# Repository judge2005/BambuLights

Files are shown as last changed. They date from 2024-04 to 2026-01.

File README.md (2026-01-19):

# Interface NeoPixels (aka Addressable LED Strip) with Bambu Lab Printers
This project uses common addressable LEDs to add additional lighting for a Bambu printer that can also show the state of the print, e.g.:
* Idle
* Printing
* Complete
* Warning
* Error

In addition it:

* Turns off the LEDs while the X1C is using LIDAR
* Syncronizes with the chamber light - if you turn it off, the additional LEDs will be turned off too
* Support GRB (WS2812x style LEDS) and RGB (APA106 style LEDs)
* Supports an arbitrary number of LEDs
* Auto-registers with Homeassistant so you can (for example) turn the lights on and off on a schedule and control whether they are reactive to the state of the printer or just white

In addition to providing extra lighting for the printer, it could just be used to provide a remote indication of the state
of the printer since it doesn't use a physical connection.
## History
I use the [BLV AMS Riser](https://makerworld.com/en/models/19535) with my Bambu Labs X1C that has a facility for adding
additional lighting, but I also like the idea of the [BLLED project](https://github.com/DutchDevelop/BLLEDController)
that adds lighting that reacts to the state of the printer. I can't use BLLED with the riser because
the LEDs are too big, but I have a lot of experience developing hardware and software that uses ESP32 and 
addressable LEDs so I developed this project to do the same thing, but for 5V WS2812B LED strips.

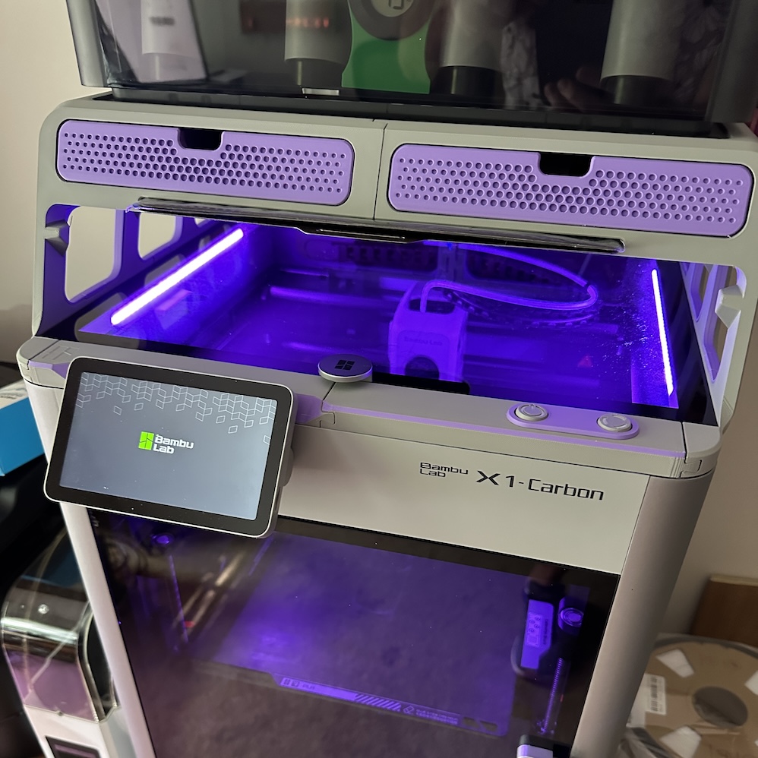
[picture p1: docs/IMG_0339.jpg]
Lights in action

# Software
This project uses PlatformIO IDE. It is easy to build and upload to the hardware if you have PlatformIO installed. Just
check out the repo and open it in PlatformIO. There are builds for three modules:

- ESP32 PICO D4 - this should work on any other 'original' ESP32 module such as the WROOM. This build uses pin 27 for the LED connection by default
- ESP32-S3 - this uses pin 16 by default
- ESP32-C3 - this uses pin 3 by default

There are two artifacts:
- firmware.bin - the firmware!
- littlefs.bin - the GUI

When the software first runs it will create an access point that you can use to connect it to your local network.
The SSID for the access point will be some hex numbers followed by _bambulights_, for example _5FC874bambulights_.
## Installing
Instead of building the software, you can install a release. Go [the latest release](https://github.com/judge2005/BambuLights/releases)
and follow the instructions.
# Hardware
The hardware is pretty simple. The LEDs take less than 0.7A total, so most ESP32 dev kits will be able to provide the
5V power for the LEDs.
## Lights
I used some [high-density WS2812B LED strips available on AliExpress](https://a.aliexpress.com/_mOUCHh0).
They are 5mm flexible LED strips with 160 LEDs/m. They have an adhesive backing so I just left the backing on
so I could slide them in to the channels in the riser. I cut them to 210mm, which is 33 LEDs. The software allows
you to specify how many LEDs you have and also change between GRB (standard for WS2812B strips) and RGB (standard for APA106 strips).

You will need to solder 28AWG hookup wire to the terminals on the strips, preferably white, red and green to match the wiring used in the original
connector. This gauge allows you to thread three wires through the channel in the riser rather than just two.

Wire the two strips in parallel.

I also bought [these JST connectors from AliExpress](https://a.aliexpress.com/_mtc1dYm) so I could easily connect/disconnect the electronics.
The wire colors match the original connector wire colors.
## Electronics
I used a [ESP32 Pico D4 devkit](https://www.amazon.com/DIYmall-ESP32-PICO-KIT-Development-Board-ESP-32/dp/B00RSPTHE0) that I happened to have lying around. The signal from these is
3.3V so I added a [CD40109B level shifter](https://www.ti.com/product/CD40109B). Again I happened to have one lying around, but pretty much any level shifter
would do.

This is how it is wired up:

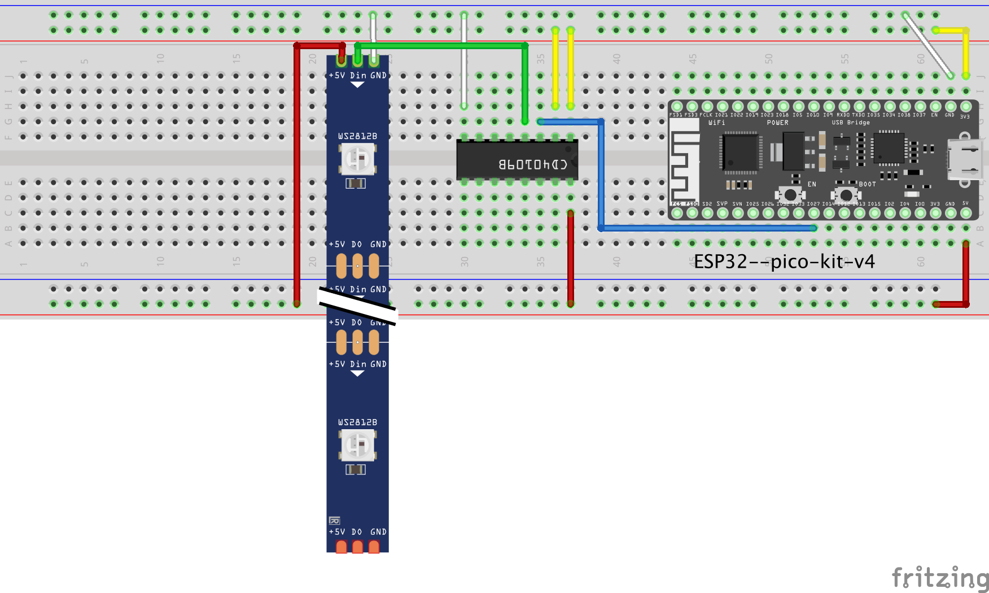
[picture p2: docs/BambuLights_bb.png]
Fritzing diagram


This is the whole thing in a box I printed for it:

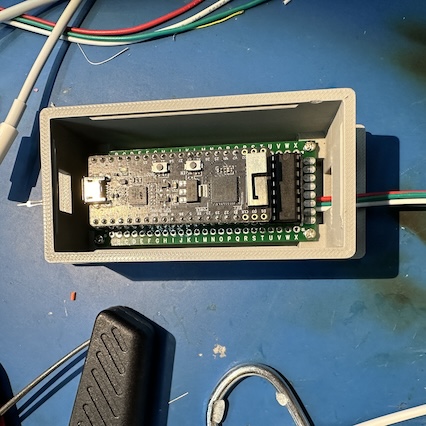
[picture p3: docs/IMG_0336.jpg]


And attached to the back of the printer:

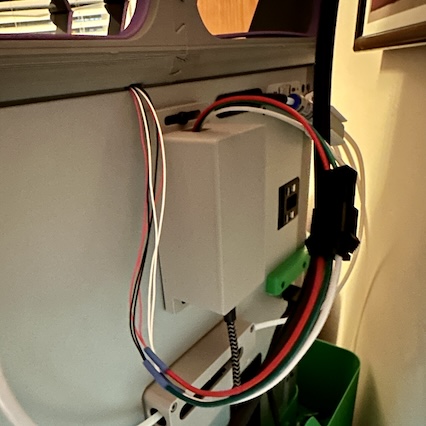
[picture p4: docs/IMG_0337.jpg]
Mounted box

# GUI
There is a web GUI that allows you to configure the printer connection, the Homeassistant connection and the colors and behaviors of the LEDs. This is
available at http://bambulights.local/ (assuming your PC/phone understands the .local suffix). When you make a
change in the GUI it will be immediately reflected in the device.

There are four screens.

The first allows you to set the colors and effects for the different printer states, and also to force the LEDs to
be on or off, and to set whether the lights are full white or reactive to the state of the printer. If you turn off the chamber light (for example with the BambuHandy app) the controller will also turn off the led strip. Similarly if you turn off the led strip with the GUI, the controller will also send a command to turn off the chamber light:

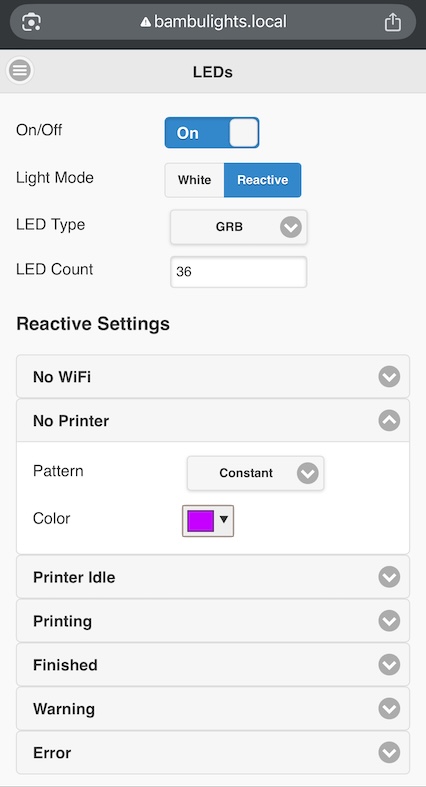
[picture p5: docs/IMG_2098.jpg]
LED controls


The second allows you to set the connection details for the printer and to change the hostname
of the device itself:

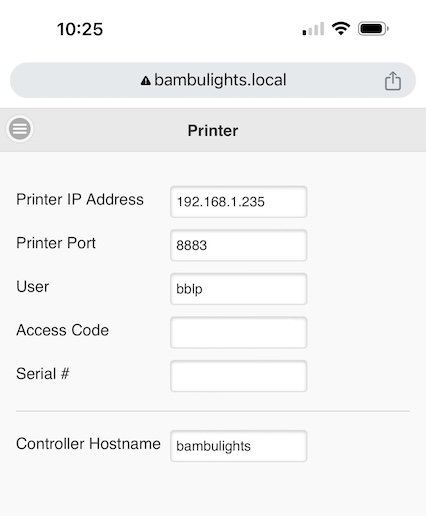
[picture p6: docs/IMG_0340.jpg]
Printer connection


The third allows you to set the connection details for Homeassistant (MQTT). When it connects the device will auto-register as _Bambu_ and you can use it
to turn the lights on and off and to change the effect (white or reactive):

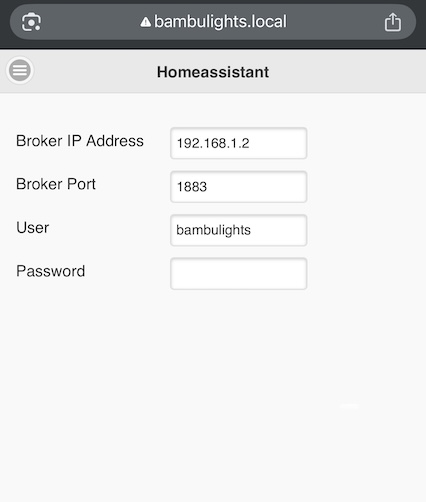
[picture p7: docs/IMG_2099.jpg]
Homeassistant connection


The last screen is for data nerds, it shows some stats about the device itself:

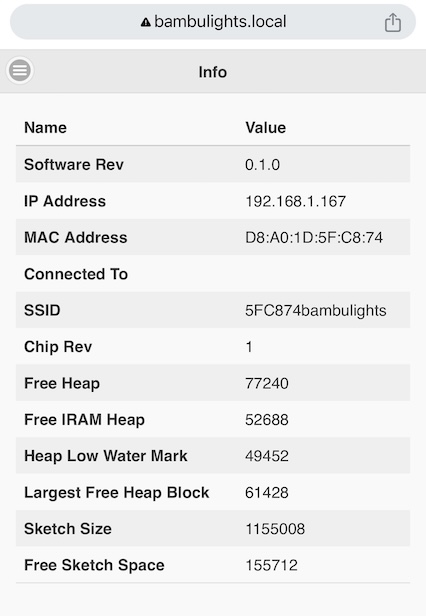
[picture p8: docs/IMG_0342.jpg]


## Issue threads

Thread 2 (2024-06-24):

IP address not found

bonninjd, 2024-06-24:
Hi, Great project.  Thank you for your work.
I programed the board, was able to connect directly and enter the wifi info, but when I enter http://bambulights.local/ in my browser, it says page can't be found.  I know my browser can handle .local addresses, as I have other projects that do this.  Any ideas?

judge2005, 2024-06-24:
Did you load the files system to the board too?On Jun 24, 2024, at 12:03 PM, bonninjd ***@***.***> wrote:
Hi, Great project.  Thank you for your work.
I programed the board, was able to connect directly and enter the wifi info, but when I enter http://bambulights.local/ in my browser, it says page can't be found.  I know my browser can handle .local addresses, as I have other projects that do this.  Any ideas?

—Reply to this email directly, view it on GitHub, or unsubscribe.You are receiving this because you are subscribed to this thread.Message ID: ***@***.***>

bonninjd, 2024-06-25:
That worked!  I used a ESP-WROOM-32 board and was trying to build a version for that.
As a future improvement, maybe adding rainbow effects and chasing as an option.
Thank you again!

judge2005, 2024-06-27:
> That worked! I used a ESP-WROOM-32 board and was trying to build a version for that. As a future improvement, maybe adding rainbow effects and chasing as an option. Thank you again!

I would like to add more effects. If you have some examples, and when they might be used, that would be useful. I think there are two general cases:

1. As a transition between states (currently a cross-fade is hard-coded). I could see a color-wipe being nice too for example.
2. As a state indication (currently just steady and pulsing).

I found this link on reddit: https://www.tweaking4all.com/hardware/arduino/adruino-led-strip-effects/

Closed 2024-06-25.

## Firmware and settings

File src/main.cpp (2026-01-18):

#include <Arduino.h>
#include <freertos/task.h>
#if ESP_ARDUINO_VERSION_MAJOR >= 3
#include "esp_mac.h"
#endif
#include <esp_wifi.h>
#include <ArduinoJson.h>
#include <SPI.h>
#include <LittleFS.h>
#include <ESPmDNS.h>
#include <AsyncWiFiManager.h>
#include <ConfigItem.h>
#include <EEPROMConfig.h>
#include <ImprovWiFi.h>
#include <Update.h>
#include <ASyncOTAWebUpdate.h>
#include "WSHandler.h"
#include "WSMenuHandler.h"
#include "WSConfigHandler.h"
#include "WSLEDConfigHandler.h"
#include "WSInfoHandler.h"
#include "MQTTBroker.h"
#include "MQTTHABroker.h"
#include "BambuLights.h"

#define DEBUG(...) { Serial.println(__VA_ARGS__); }
#ifndef DEBUG
#define DEBUG(...) {  }
#endif

static String TRUE_STRING("true");
static String FALSE_STRING("false");

const char *manifest[]{
    // Firmware name
    "Bambu Lighting",
    // Firmware version
    "0.4.5",
    // Hardware chip/variant
#if defined(CONFIG_IDF_TARGET_ESP32)
    "ESP32",
#elif defined(CONFIG_IDF_TARGET_ESP32S3)
	"ESP32-S3",
#elif defined(CONFIG_IDF_TARGET_ESP32S2)
	"ESP32-S2",
#elif defined(CONFIG_IDF_TARGET_ESP32C3)
	"ESP32-C3",
#elif defined(CONFIG_IDF_TARGET_ESP32C6)
	"ESP32-C6",
#else
	"Unknown",
#endif
    // Device name
    "Bambu"
};

StringConfigItem hostName("hostname", 63, "bambulights");
AsyncWebServer server(80);
AsyncWebSocket ws("/ws"); // access at ws://[esp ip]/ws
DNSServer dns;
AsyncWiFiManager wifiManager(&server, &dns);
ASyncOTAWebUpdate otaUpdater(Update, "update", "secretsauce");
AsyncWiFiManagerParameter *hostnameParam;
MQTTBroker mqttBroker;
MQTTHABroker mqttHABroker;
BambuLights *bambuLights;

SemaphoreHandle_t wsMutex;

TaskHandle_t wifiManagerTask;
TaskHandle_t improvTask;
TaskHandle_t ledTask;
TaskHandle_t commitEEPROMTask;

String ssid = "BambuLights";

BaseConfigItem* mqttConfigSet[] = {
  &hostName,
  &MQTTBroker::getHost(),
  &MQTTBroker::getUser(),
  &MQTTBroker::getPassword(),
  &MQTTBroker::getPort(),
  &MQTTBroker::getSerialNumber(),
  0
};

CompositeConfigItem mqttConfig("mqtt", 0, mqttConfigSet);

BaseConfigItem* mqttHAConfigSet[] = {
  &MQTTHABroker::getHost(),
  &MQTTHABroker::getUser(),
  &MQTTHABroker::getPassword(),
  &MQTTHABroker::getPort(),
  0
};

CompositeConfigItem mqttHAConfig("mqtt_ha", 0, mqttHAConfigSet);

BaseConfigItem* rootConfigSet[] = {
  &mqttConfig,
  &mqttHAConfig,
  &BambuLights::getAllConfig(),
  0
};

CompositeConfigItem rootConfig("root", 0, rootConfigSet);

EEPROMConfig config(rootConfig);

// Declare some functions
void setWiFiCredentials(const char *ssid, const char *password);
void setWiFiAP(bool);
void infoCallback();
void broadcastUpdate(String originalKey, String& originalValue);
void broadcastUpdate(String originalKey, const BaseConfigItem& item);

String getChipId(void)
{
	uint8_t macid[6];

	esp_efuse_mac_get_default(macid);
	String chipId = String((uint32_t)(macid[5] + (((uint32_t)(macid[4])) << 8) + (((uint32_t)(macid[3])) << 16)), HEX);
	chipId.toUpperCase();
	return chipId;
}

String chipId = getChipId();

void createSSID() {
	// Create a unique SSID that includes the hostname. Max SSID length is 32!
	ssid = (chipId + hostName).substring(0, 31);
}

void improvTaskFn(void *pArg)
{
  ImprovWiFi improvWiFi(
      manifest[0],
      manifest[1],
      manifest[2],
      manifest[3]);

  // improvWiFi.setInfoCallback([](const char *msg) {tfts->setStatus(msg);});
  improvWiFi.setWiFiCallback(setWiFiCredentials);

  DEBUG("Running improv");

  while (true)
  {
    xSemaphoreTake(wsMutex, portMAX_DELAY);
    improvWiFi.loop();
    xSemaphoreGive(wsMutex);

    delay(10);
  }
}

void onLedTypeChanged(ConfigItem<byte> &item) {
	bambuLights->updatePixelCount();
}

std::function<void()> lightModeChanged = [](){};

void setLightModeChangeCallback(std::function<void()> callback) {
	lightModeChanged = callback;
}

void onLightModeChanged(ConfigItem<byte> &item) {
	lightModeChanged();
}

std::function<void()> lightStateChanged = [](){};

void setLightStateChangeCallback(std::function<void()> callback) {
	lightStateChanged = callback;
}

void onLightStateChanged(ConfigItem<boolean> &lightState) {
	lightStateChanged();
	if (BambuLights::getChamberSync()) {
		mqttBroker.setChamberLight(lightState);
	}
}

void onChamberSyncChanged(ConfigItem<boolean> &chamberSync) {
	if (chamberSync) {
		mqttBroker.setChamberLight(BambuLights::getLightState());
	}
}

void onNumLedsChanged(ConfigItem<byte> &item) {
	bambuLights->updatePixelCount();
}

template<class T>
void onMqttParamsChanged(ConfigItem<T> &item) {
	mqttBroker.init(ssid);
}

template<class T>
void onMqttHAParamsChanged(ConfigItem<T> &item) {
	mqttHABroker.init(ssid);
}

template<class T>
void onHostnameChanged(ConfigItem<T> &item) {
	config.commit();
	ESP.restart();
}

void ledTaskFn(void *pArg) {
	bambuLights->begin();
	BambuLights::State prevLightsState = BambuLights::noWiFi;
	long startIdleTimeMs = 0;
	bool inFinishedPhase = false;
	bool doorWasOpen = false;
	bool chamberLightWasOn = true;

	while (true) {
		mqttBroker.checkConnection();
		mqttHABroker.checkConnection();

		bambuLights->setBrightness(255);	// Brightness scale factor

		BambuLights::State lightsState = BambuLights::noWiFi;

		if (WiFi.isConnected()) {		
			// Run the state machine
			switch (mqttBroker.getState()) {
				case MQTTBroker::disconnected:
					lightsState = BambuLights::noPrinter;
					break;
				case MQTTBroker::idle:
					{
						lightsState = BambuLights::printer;

						if (prevLightsState == BambuLights::printing && !inFinishedPhase) {
							inFinishedPhase = true;
							startIdleTimeMs = millis();
							lightsState = BambuLights::finished;
						}

						if (inFinishedPhase) {
							lightsState = BambuLights::finished;

							// Switch to normal idle lights if timed out
							if (BambuLights::getIdleTimeout() > 0 && (millis() - startIdleTimeMs > BambuLights::getIdleTimeout() * 60000)) {
								lightsState = BambuLights::printer;
								inFinishedPhase = false;
							}

							// Switch to normal idle lights if door is opened after print complete
							if (!doorWasOpen && mqttBroker.isDoorOpen()) {
								lightsState = BambuLights::printer;
								inFinishedPhase = false;
							}
						}
					}
					break;
				case MQTTBroker::printing:
					lightsState = BambuLights::printing;
					break;
				case MQTTBroker::no_lights:
					lightsState = BambuLights::no_lights;
					break;
				case MQTTBroker::warning:
					lightsState = BambuLights::warning;
					break;
				case MQTTBroker::error:
					lightsState = BambuLights::error;
					break;
			}

			prevLightsState = lightsState;
			doorWasOpen = mqttBroker.isDoorOpen();

			boolean chamberLightIsOn = mqttBroker.isLightOn();
            if (chamberLightIsOn != chamberLightWasOn) {
				chamberLightWasOn = chamberLightIsOn;
				if (BambuLights::getChamberSync() && (BambuLights::getLightState() != chamberLightIsOn)) {
					BambuLights::getLightState() = chamberLightIsOn;
					BambuLights::getLightState().notify();
					broadcastUpdate(BambuLights::getLightState().name, BambuLights::getLightState());
				}
			}

			// Override the results if told to
			if (!BambuLights::getLightState()) {
				lightsState = BambuLights::no_lights;
			} else {
				if (BambuLights::getLightMode() == 0) {
					lightsState = BambuLights::white;
				}
			}
		}

		bambuLights->setState(lightsState);

		bambuLights->loop();

		delay(16);
	}
}

void setWiFiCredentials(const char *ssid, const char *password)
{
  WiFi.disconnect();
  wifiManager.setRouterCredentials(ssid, password);
  wifiManager.connect();
}

void sendUpdateForm(AsyncWebServerRequest *request) {
	request->send(LittleFS, "/update.html");
}

void sendUpdatingInfo(AsyncResponseStream *response, boolean hasError) {
  response->print("<html><head><meta http-equiv=\"refresh\" content=\"10; url=/\"></head><body>");

  hasError ?
      response->print("Update failed: please wait while the device reboots") :
      response->print("Update OK: please wait while the device reboots");

  response->print("</body></html>");
}

void sendFavicon(AsyncWebServerRequest *request) {
	DEBUG("Got favicon request")
	request->send(LittleFS, "/assets/favicon-32x32.png", "image/png");
}

String* items[] {
	&WSMenuHandler::ledsMenu,
	&WSMenuHandler::mqttMenu,
	&WSMenuHandler::mqttHAMenu,
	&WSMenuHandler::infoMenu,
	0
};

WSMenuHandler wsMenuHandler(items);
WSConfigHandler wsMqttHandler(rootConfig, "mqtt");
WSConfigHandler wsMqttHAHandler(rootConfig, "mqtt_ha");
WSLEDConfigHandler wsLEDHandler(rootConfig, "leds");
WSInfoHandler wsInfoHandler(infoCallback);

// Order of this needs to match the numbers in WSMenuHandler.cpp
WSHandler* wsHandlers[] {
	&wsMenuHandler,
	&wsLEDHandler,
	&wsMqttHandler,
	&wsMqttHAHandler,
	&wsInfoHandler,
	NULL,
	NULL,
	NULL
};


void infoCallback() {
	wsInfoHandler.setSsid(ssid);
	wsInfoHandler.setRevision(manifest[1]);

	wsInfoHandler.setFSSize(String(LittleFS.totalBytes()));
	wsInfoHandler.setFSFree(String(LittleFS.totalBytes() - LittleFS.usedBytes()));

	wsInfoHandler.setHostname(hostName);
}

void broadcastUpdate(String originalKey, String& originalValue) {
	xSemaphoreTake(wsMutex, portMAX_DELAY);

	JsonDocument doc;
	JsonObject root = doc.to<JsonObject>();

	root["type"] = "sv.update";

	JsonVariant value = root.createNestedObject("value");
	value[originalKey] = serialized(originalValue.c_str());

	size_t len = measureJson(root);
	AsyncWebSocketMessageBuffer * buffer = ws.makeBuffer(len);
	if (buffer) {
		serializeJson(root, (char *)buffer->get(), len);
		ws.textAll(buffer);
	}

	xSemaphoreGive(wsMutex);
}

void broadcastUpdate(String originalKey, const BaseConfigItem& item) {
	String rawJSON = item.toJSON();
	broadcastUpdate(originalKey, rawJSON);
}

void updateValue(String originalKey, String _key, String value, BaseConfigItem *item) {
	int index = _key.indexOf('-');
	if (index == -1) {
		const char* key = _key.c_str();
		item = item->get(key);
		if (item != 0) {
			item->fromString(value);
			item->put();

			// Order of below is important to maintain external consistency
			broadcastUpdate(originalKey, *item);
			item->notify();
		} else if (_key == "wifi_ap") {
			setWiFiAP(value == TRUE_STRING ? true : false);
		}
	} else {
		String firstKey = _key.substring(0, index);
		String nextKey = _key.substring(index+1);
		updateValue(originalKey, nextKey, value, item->get(firstKey.c_str()));
	}
}

void updateValue(int screen, String pair) {
	int index = pair.indexOf(':');
	DEBUG(pair)
	// _key has to hang around because key points to an internal data structure
	String _key = pair.substring(0, index);
	String value = pair.substring(index+1);

	updateValue(_key, _key, value, &rootConfig);
}

/*
 * Handle application protocol
 */
void handleWSMsg(AsyncWebSocketClient *client, char *data) {
	String wholeMsg(data);
	int code = wholeMsg.substring(0, wholeMsg.indexOf(':')).toInt();

	if (code < 9) {
		wsHandlers[code]->handle(client, data);
	} else {
		String message = wholeMsg.substring(wholeMsg.indexOf(':')+1);
		int screen = message.substring(0, message.indexOf(':')).toInt();
		String pair = message.substring(message.indexOf(':')+1);
		updateValue(screen, pair);
	}
}

/*
 * Handle transport protocol
 */
void wsHandler(AsyncWebSocket *server, AsyncWebSocketClient *client, AwsEventType type, void *arg, uint8_t *data, size_t len) {
	//Handle WebSocket event
	switch (type) {
	case WS_EVT_CONNECT:
		DEBUG("WS connected")
		;
		break;
	case WS_EVT_DISCONNECT:
		DEBUG("WS disconnected")
		;
		break;
	case WS_EVT_ERROR:
		DEBUG("WS error")
		;
		DEBUG((char* )data)
		;
		break;
	case WS_EVT_PONG:
		DEBUG("WS pong")
		;
		break;
	case WS_EVT_DATA:	// Yay we got something!
		DEBUG("WS data")
		;
		AwsFrameInfo * info = (AwsFrameInfo*) arg;
		if (info->final && info->index == 0 && info->len == len) {
			//the whole message is in a single frame and we got all of it's data
			if (info->opcode == WS_TEXT) {
				DEBUG("WS text data");
				data[len] = 0;
				handleWSMsg(client, (char *) data);
			} else {
				DEBUG("WS binary data");
			}
		} else {
			DEBUG("WS data was split up!");
		}
		break;
	}
}

void mainHandler(AsyncWebServerRequest *request) {
	DEBUG("Got request")
	request->send(LittleFS, "/index.html");
}

void configureWebServer() {
	server.serveStatic("/", LittleFS, "/");
	server.on("/", HTTP_GET, mainHandler).setFilter(ON_STA_FILTER);
	server.on("/assets/favicon-32x32.png", HTTP_GET, sendFavicon);
	server.serveStatic("/assets", LittleFS, "/assets");
	otaUpdater.init(server, "/update", sendUpdateForm, sendUpdatingInfo);

	// attach AsyncWebSocket
	ws.onEvent(wsHandler);
	server.addHandler(&ws);
	server.begin();
	ws.enable(true);
}

void setWiFiAP(bool on) {
	if (on) {
		wifiManager.startConfigPortal(ssid.c_str(), "secretsauce");
	} else {
		wifiManager.stopConfigPortal();
	}
}

void SetupServer() {
	DEBUG("SetupServer()");
	hostName = String(hostnameParam->getValue());
	hostName.put();
	config.commit();
	createSSID();
	wifiManager.setAPCredentials(ssid.c_str(), "secretsauce");
	DEBUG(hostName.value);
	MDNS.begin(hostName.value.c_str());
  MDNS.addService("http", "tcp", 80);

//	getTime();
}

void commitEEPROMTaskFn(void *pArg) {
	while(true) {
		delay(60000);
		Serial.println("Committing config");
		config.commit();
	}
}

void initFromEEPROM() {
//	config.setDebugPrint(debugPrint);
	config.init();
//	rootConfig.debug(debugPrint);
	DEBUG(hostName);
	rootConfig.get();	// Read all of the config values from EEPROM
	DEBUG(hostName);

	hostnameParam = new AsyncWiFiManagerParameter("Hostname", "device host name", hostName.value.c_str(), 63);
}

void connectedHandler() {
	DEBUG("connectedHandler");
	wifi_ps_type_t wifi_ps_mode;
	esp_wifi_get_ps(&wifi_ps_mode);
	DEBUG(wifi_ps_mode);
	MDNS.end();
	MDNS.begin(hostName.value.c_str());
	MDNS.addService("http", "tcp", 80);
}

void apChange(AsyncWiFiManager *wifiManager) {
	DEBUG("apChange()");
	DEBUG(wifiManager->isAP());
	wifi_ps_type_t wifi_ps_mode;
	esp_wifi_get_ps(&wifi_ps_mode);
	DEBUG(wifi_ps_mode);
//	esp_wifi_set_ps(WIFI_PS_NONE);
//	broadcastUpdate(wifiCallback());
}

void wifiManagerTaskFn(void *pArg) {

	while(true) {
		xSemaphoreTake(wsMutex, portMAX_DELAY);
		wifiManager.loop();
		xSemaphoreGive(wsMutex);

		delay(50);
	}
}

void setup()
{
	/*
	 * setup() runs on core 1
	 */
  Serial.begin(115200);
  Serial.setDebugOutput(true);

	wsMutex = xSemaphoreCreateMutex();

	createSSID();

	EEPROM.begin(2048);
	initFromEEPROM();

	LittleFS.begin();

	bambuLights = new BambuLights(LED_PIN);

  xTaskCreatePinnedToCore(
    commitEEPROMTaskFn,   /* Function to implement the task */
    "Commit EEPROM task", /* Name of the task */
    2048,                 /* Stack size in words */
    NULL,                 /* Task input parameter */
    tskIDLE_PRIORITY,     /* More than background tasks */
    &commitEEPROMTask,    /* Task handle. */
    xPortGetCoreID());

  xTaskCreatePinnedToCore(
		ledTaskFn, /* Function to implement the task */
		"led task", /* Name of the task */
		4096,  /* Stack size in words */
		NULL,  /* Task input parameter */
		tskIDLE_PRIORITY + 2,  /* Priority of the task (idle) */
		&ledTask,  /* Task handle. */
#if portNUM_PROCESSORS > 1
		1
#else
		0
#endif
	);

  xTaskCreatePinnedToCore(
		improvTaskFn, /* Function to implement the task */
		"Improv task", /* Name of the task */
		2048,  /* Stack size in words */
		NULL,  /* Task input parameter */
		tskIDLE_PRIORITY + 1,  /* More than background tasks */
		&improvTask,  /* Task handle. */
		0
	);
	
  wifiManager.setDebugOutput(true);
  wifiManager.setHostname(hostName.value.c_str()); // name router associates DNS entry with
  wifiManager.setCustomOptionsHTML("<br><form action='/t' name='time_form' method='post'><button name='time' onClick=\"{var now=new Date();this.value=now.getFullYear()+','+(now.getMonth()+1)+','+now.getDate()+','+now.getHours()+','+now.getMinutes()+','+now.getSeconds();} return true;\">Set Clock Time</button></form><br><form action=\"/app.html\" method=\"get\"><button>Configure Clock</button></form>");
  wifiManager.addParameter(hostnameParam);
  wifiManager.setSaveConfigCallback(SetupServer);
  wifiManager.setConnectedCallback(connectedHandler);
  wifiManager.setConnectTimeout(2000); // milliseconds
  wifiManager.setAPCallback(apChange);
  wifiManager.setAPCredentials(ssid.c_str(), "secretsauce");
  wifiManager.start();

  configureWebServer();

   /*
	* Very occasionally the wifi stack will close with a beacon timeout error.
	*
	* This is apparently related to it not being able to allocate a buffer at
	* some point because of a transitory memory issue.
	*
	* In older versions this issue is not well handled so the wifi stack never
	* recovers. The work-around is to not allow the wifi radio to sleep.
	*
	* https://github.com/espressif/esp-idf/issues/11615
	*/
  esp_wifi_set_ps(WIFI_PS_NONE);

  xTaskCreatePinnedToCore(
    wifiManagerTaskFn,    /* Function to implement the task */
    "WiFi Manager task",  /* Name of the task */
    4096,                 /* Stack size in words */
    NULL,                 /* Task input parameter */
    tskIDLE_PRIORITY + 2, /* Priority of the task (idle) */
    &wifiManagerTask,     /* Task handle. */
    0);

	hostName.setCallback(onHostnameChanged);
	BambuLights::getLedType().setCallback(onLedTypeChanged);
	BambuLights::getNumLEDs().setCallback(onNumLedsChanged);
	BambuLights::getLightMode().setCallback(onLightModeChanged);
	BambuLights::getLightState().setCallback(onLightStateChanged);
	BambuLights::getChamberSync().setCallback(onChamberSyncChanged);

	MQTTBroker::getHost().setCallback(onMqttParamsChanged);
	MQTTBroker::getPort().setCallback(onMqttParamsChanged);
	MQTTBroker::getUser().setCallback(onMqttParamsChanged);
	MQTTBroker::getPassword().setCallback(onMqttParamsChanged);
	MQTTBroker::getSerialNumber().setCallback(onMqttParamsChanged);
	mqttBroker.init(ssid);

	MQTTHABroker::getHost().setCallback(onMqttHAParamsChanged);
	MQTTHABroker::getPort().setCallback(onMqttHAParamsChanged);
	MQTTHABroker::getUser().setCallback(onMqttHAParamsChanged);
	MQTTHABroker::getPassword().setCallback(onMqttHAParamsChanged);
	mqttHABroker.init(ssid);

  Serial.print("setup() running on core ");
  Serial.println(xPortGetCoreID());

  vTaskDelete(NULL);	// Delete this task (so loop() won't be called)
}

void loop()
{
  // Should never be called
}

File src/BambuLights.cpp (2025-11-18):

#include "BambuLights.h"
#include <math.h>

//#define DEBUG_COLORS
//#define DEBUG_FADE

CompositeConfigItem& BambuLights::getNoWiFiConfig() {
    static BooleanConfigItem colors("colors", true);  // Collapsed
    static ByteConfigItem pattern("pattern", pulse);
    static IntConfigItem  hue("hue", 203);
    static ByteConfigItem value("value", 255);
    static ByteConfigItem saturation("saturation", 255);
    static ByteConfigItem pulse_per_min("pulse_per_min", 10);

    static BaseConfigItem* configSet[] {
        &colors,
        &pattern,
        &hue,
        &value,
        &saturation,
        &pulse_per_min,
        0
    };

    static CompositeConfigItem config("noWiFi", 0, configSet);

    return config;
}

CompositeConfigItem& BambuLights::getNoPrinterConnectedConfig() {
    static BooleanConfigItem colors("colors", true);  // Collapsed
    static ByteConfigItem pattern("pattern", constant);
    static IntConfigItem  hue("hue", 203);
    static ByteConfigItem value("value", 255);
    static ByteConfigItem saturation("saturation", 255);
    static ByteConfigItem pulse_per_min("pulse_per_min", 7);

    static BaseConfigItem* configSet[] {
        &colors,
        &pattern,
        &hue,
        &value,
        &saturation,
        &pulse_per_min,
        0
    };

    static CompositeConfigItem config("noPrinterConnected", 0, configSet);

    return config;
}

CompositeConfigItem& BambuLights::getPrinterConnectedConfig() {
    static BooleanConfigItem colors("colors", true);  // Collapsed
    static ByteConfigItem pattern("pattern", constant);
    static IntConfigItem  hue("hue", 0);
    static ByteConfigItem value("value", 128);
    static ByteConfigItem saturation("saturation", 0);
    static ByteConfigItem pulse_per_min("pulse_per_min", 7);

    static BaseConfigItem* configSet[] {
        &colors,
        &pattern,
        &hue,
        &value,
        &saturation,
        &pulse_per_min,
        0
    };

    static CompositeConfigItem config("printerConnected", 0, configSet);

    return config;
}

CompositeConfigItem& BambuLights::getPrintingConfig() {
    static BooleanConfigItem colors("colors", true);  // Collapsed
    static ByteConfigItem pattern("pattern", constant);
    static IntConfigItem  hue("hue", 0);
    static ByteConfigItem value("value", 255);
    static ByteConfigItem saturation("saturation", 0);
    static ByteConfigItem pulse_per_min("pulse_per_min", 7);

    static BaseConfigItem* configSet[] {
        &colors,
        &pattern,
        &hue,
        &value,
        &saturation,
        &pulse_per_min,
        0
    };

    static CompositeConfigItem config("printing", 0, configSet);

    return config;
}

CompositeConfigItem& BambuLights::getErrorConfig() {
    static BooleanConfigItem colors("colors", true);  // Collapsed
    static ByteConfigItem pattern("pattern", pulse);
    static IntConfigItem  hue("hue", 0);
    static ByteConfigItem value("value", 255);
    static ByteConfigItem saturation("saturation", 255);
    static ByteConfigItem pulse_per_min("pulse_per_min", 7);

    static BaseConfigItem* configSet[] {
        &colors,
        &pattern,
        &hue,
        &value,
        &saturation,
        &pulse_per_min,
        0
    };

    static CompositeConfigItem config("error", 0, configSet);

    return config;
}

CompositeConfigItem& BambuLights::getWarningConfig() {
    static BooleanConfigItem colors("colors", true);  // Collapsed
    static ByteConfigItem pattern("pattern", constant);
    static IntConfigItem  hue("hue", 171);
    static ByteConfigItem value("value", 255);
    static ByteConfigItem saturation("saturation", 255);
    static ByteConfigItem pulse_per_min("pulse_per_min", 7);

    static BaseConfigItem* configSet[] {
        &colors,
        &pattern,
        &hue,
        &value,
        &saturation,
        &pulse_per_min,
        0
    };

    static CompositeConfigItem config("warning", 0, configSet);

    return config;
}

CompositeConfigItem& BambuLights::getFinishedConfig() {
    static BooleanConfigItem colors("colors", true);  // Collapsed
    static ByteConfigItem pattern("pattern", constant);
    static IntConfigItem  hue("hue", 63);
    static ByteConfigItem value("value", 255);
    static ByteConfigItem saturation("saturation", 255);
    static ByteConfigItem pulse_per_min("pulse_per_min", 7);

    static BaseConfigItem* configSet[] {
        &colors,
        &pattern,
        &hue,
        &value,
        &saturation,
        &pulse_per_min,
        &getIdleTimeout(),
        0
    };

    static CompositeConfigItem config("finished", 0, configSet);

    return config;
}

CompositeConfigItem& BambuLights::getAllConfig() {
    static BaseConfigItem* configSet[] {
        &getNoWiFiConfig(),
        &getNoPrinterConnectedConfig(),
        &getPrinterConnectedConfig(),
        &getPrintingConfig(),
        &getErrorConfig(),
        &getWarningConfig(),
        &getFinishedConfig(),
        &getLedType(),
        &getNumLEDs(),
        &getLightMode(),
        &getLightState(),
        &getChamberSync(),
	      0
    };

    static CompositeConfigItem config("leds", 0, configSet);

    return config;
};

BambuLights::BambuLights(int pin) :
    pixels(new NeoPixelBus <NeoGrbFeature, Neo800KbpsMethod>(getNumLEDs(), pin)),
    pin(pin),
    currentState(noWiFi)
{
    setCurrentConfig(getNoWiFiConfig());
}

void BambuLights::updatePixelCount() {
  if (pixels->PixelCount() != getNumLEDs()) {
    pixels->ClearTo(0);
    show();
    pixels->Dirty();
    show();
    delete pixels;
    pixels = new NeoPixelBus <NeoGrbFeature, Neo800KbpsMethod>(getNumLEDs(), pin);
    begin();
  }
}

void BambuLights::setState(State state) {
  if (currentState != state) {
    currentState = state;
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

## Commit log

2024-04-29 Fix pulse animation and add cross-fading when changing LED state
    [BambuLights.cpp, MQTTBroker.cpp]
2024-05-01 Fix cross-fading to/from a pulsing pattern
    [BambuLights.cpp]
2024-05-01 Fix ws broadcast of changes to nested properties
    [main.cpp]
2024-05-12 Fix number of LEDs
    [main.cpp]
2024-05-24 Allow the device hostname to be changed from the web page
2024-05-25 Add some documentation assets
    [BambuLights.fzz]
2024-05-27 Add sample MQTT message and output of https://e.bambulab.com/query.php?lang=en
2024-05-27 Detect more errors and warnings. Turn off print finished state if door is opened
    [MQTTBroker.cpp, main.cpp]
2025-01-25 make number and type of leds configurable
2025-01-26 Fix persistence issue with new led configfs
    [BambuLights.cpp, WSLEDConfigHandler.cpp, main.cpp]
2025-02-24 Control built-in chamber light
2025-03-15 If chamber lights are turned off, turn off led strip too
2025-11-18 Add control to sync with chamber light. Use availability topic with HA
2025-11-22 Add general state MQTT topic and chamber light control
2025-11-22 Publish state as sensors to HA
2025-11-23 Fixed HA printer state icon
    [MQTTHABroker.cpp]
2026-01-05 Add example build for a board other than the ESP32 pico
    [partitions_new.csv]
2026-01-08 Add ESP32 C3 build to platformio.ini
2026-01-11 Tweak to ESP32 C3 support
2026-01-19 Add builds for the ESP32-S3 and ESP32-C3
